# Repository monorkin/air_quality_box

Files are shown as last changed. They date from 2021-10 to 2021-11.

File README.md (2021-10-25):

# Air Quality Box

This is a [ESPHome](https://esphome.io/) powered (integrated
with [Home Assistant](https://www.home-assistant.io/))
in-door air quality meter with a display.

It measures:
* **CO₂ concentration**
* **Relative humidity**
* **Temperature**
* **Atmospheric pressure**
* **Air conductivity**
* **Dust particles <1µm weight concentration**
* **Dust particles <2.5µm weight concentration**
* **Dust particles <4µm weight concentration**
* **Dust particles <10µm weight concentration**

## Assembly

This project is split into three parts, each with it's own steps:
1. [Printed circuit board](./pcb/)
2. [Firmware](./firmware/)
3. [3D printed case](./case/)

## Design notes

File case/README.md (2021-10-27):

# Case

The case houses all components in an enclosure that can be hung from a wall or
which can sit on a table.

It also enables secure mounting of some sensors by providing screw anchors for
them.

## Development

The case is developed using [FreeCad](https://www.freecadweb.org/downloads.php).
The project also contains STL files for each component of the case.

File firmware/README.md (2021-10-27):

# Firmware

The firmware is a program that drives all sensors, connects to your WiFi
network, does OTA updates, and interacts with Home Assistant.

It's a single piece of software that controls all the device does.

## Building & flashing the firmware

The firmware is built and flashed using the
[`esphome` tool](https://esphome.io/guides/getting_started_command_line.html).

Once `esphome` is installed on your machine, open a terminal and navigate to
the `/firmware` directory of this project.

First, we want to configure the passwords for your device. These include your
WiFi password so that the device can connect to your network.

To do this, copy the `secrets.sample.yaml` file, paste it to the directory and
rename it to `secrets.yaml`. Open it in any editor and change the values to
your liking.

Second, we have to build and flash the firmware.
To do that, connect the device to your computer via USB, then run
`esphome run ./air_quality_box.yaml`. The tool will go through the
process of fetching all dependencies, building and flashing the firmware to the
device.

When prompted with a question of how you want to flash the device
(via WiFi/OTA or USB) choose USB and hit `Enter`.

The process will show you a percentage progress indicator, once it reaches
`100%` the device is ready to use, but the process won't terminate and will
display you all logs form the device. You can just `Ctrl`+`C` out of the
process at that point and un-plug the device.

## Updating the firmware

To update the firmware you just have to run `esphome run ./air_quality_box.yaml`
again.

If your device is connected to the same WiFi as your computer then you can
choose `Wifi`, or `OTA`, or `air-quality-box.local` from the prompt.

If the device isn't connected to you WiFi then you will have to connect it via
USB.

## Troubleshooting

### SPS30 (particle/dust sensor) reading abnormally high values

This can be a problem with sensors bought from some sellers.

The readings are abnormally high because the sensor is full of dust (which got
there either while shipping, storage or acquisition).

To fix this the auto-cleaning routine needs to be run on the device.
This can be done manually, but it's also configured to run after the device
has been powered on for longer than 7 days.

The ESPHome SPS30 component currently doesn't support triggering auto-cleaning
nor changing the auto-cleaning interval. Therefore, if you want to change these
values you will have to install the
[Arduino IDE](https://www.arduino.cc/en/software)
on your machine,
add [paulvha's SPS30 library](https://github.com/paulvha/sps30),
and then flash the
[Example 2: SPS30 Basic Readings - Auto-clean](https://github.com/paulvha/sps30/blob/master/examples/Example2_sps30_BasicReadings_autoclean/Example2_sps30_BasicReadings_autoclean.ino)
sketch. In it you can trigger auto-cleaning and change the auto-clean interval -
read the comments in the sketch, they will guide you through everything you need
do or set (remember to switch to I2C communication!).

### SPS30 (particle/dust sensor) reading the same value for all or some particle size ranges

First, give the device some time to settle in. About 1 to 3h should be enough.

Second, this is somewhat normal depending on the relative humidity of your room.

All cheap, laser-based, particle sensors face this problem in high-humidity
environments. The particles/dust in the air absorb some of the humidity, or the
humidity can condense on the particles, which makes them look simultaneously
the correct size and larger to the sensor as they scatter and diffract light.

This artificially inflates the numbers of larger particles to the point that
they can be the same as the numbers of smaller particles (up to the 2nd decimal).

If you are concerned about your sensor not working correctly, check the device
logs using `esphome logs ./air_quality_box.yaml` to see all 6 decimal places for
each measurement. They should be different somewhere after the 2nd decimal
place.

Note that all values after the 2nd decimal place in a reading are mostly noise
and are therefore discarded.

### MH-Z19B (CO₂ sensor) reading abnormally high or low values

Initial high readings are normal for this sensor. It will need about 1 to 3h so
settle in and auto-calibrate itself.

Just be patient.

### MH-Z19B (CO₂ sensor) flat-lines at 400ppm

That's a limitation of the sensor. It can't measure anything below 400ppm CO₂.

### The device doesn't show up in Home Assistant

Double check that you entered your WiFi credentials correctly in `secrets.yaml`.

If the device failed to connect to your WiFi it will create it's own hotspot
names `Air-Quality-Box Fallback Hotspot`. Try looking for it and connecting to
it to configure the WiFi credentials correctly, or try correcting them in
`secrets.yaml` and re-flashing the device with
`esphome run ./air_quality_box.yaml`.

Also, check that Home Assistant can see and communicate with the devices on
the WiFi network you connected this device to.

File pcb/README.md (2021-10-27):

# PCB

The PCB connects all components into a single device.
It routes power and signals from the micro-controller to each sensor, and it
does some basic power filtering.

## Development

The PCB is developed using [KiCad v5](https://www.kicad.org/download/).
All symbols, footprints and models can only be from the standard library or
contained within this project.

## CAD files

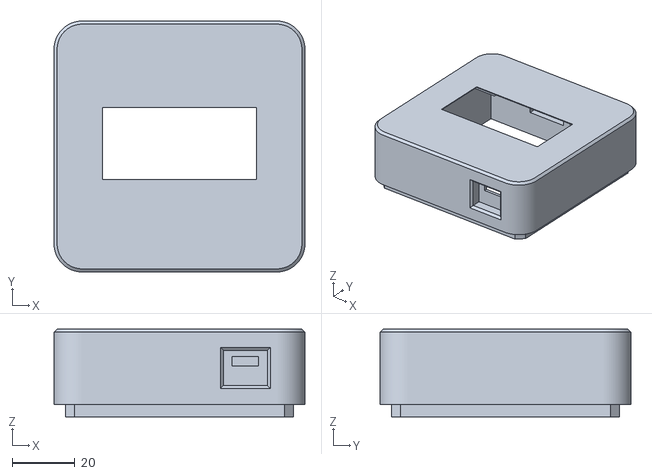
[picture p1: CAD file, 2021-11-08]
case/out/air_qualty_box-top_piece_whole.stl
80.0 x 80.0 x 28.0

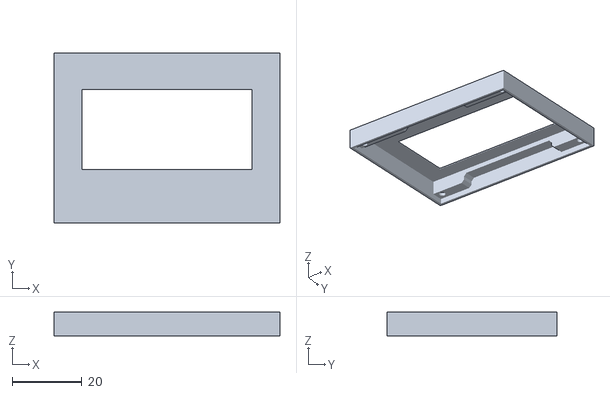
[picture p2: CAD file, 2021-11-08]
case/out/air_qualty_box-top_piece.stl
65.0 x 49.0 x 6.80

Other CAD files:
case/air_qualty_box.FCStd

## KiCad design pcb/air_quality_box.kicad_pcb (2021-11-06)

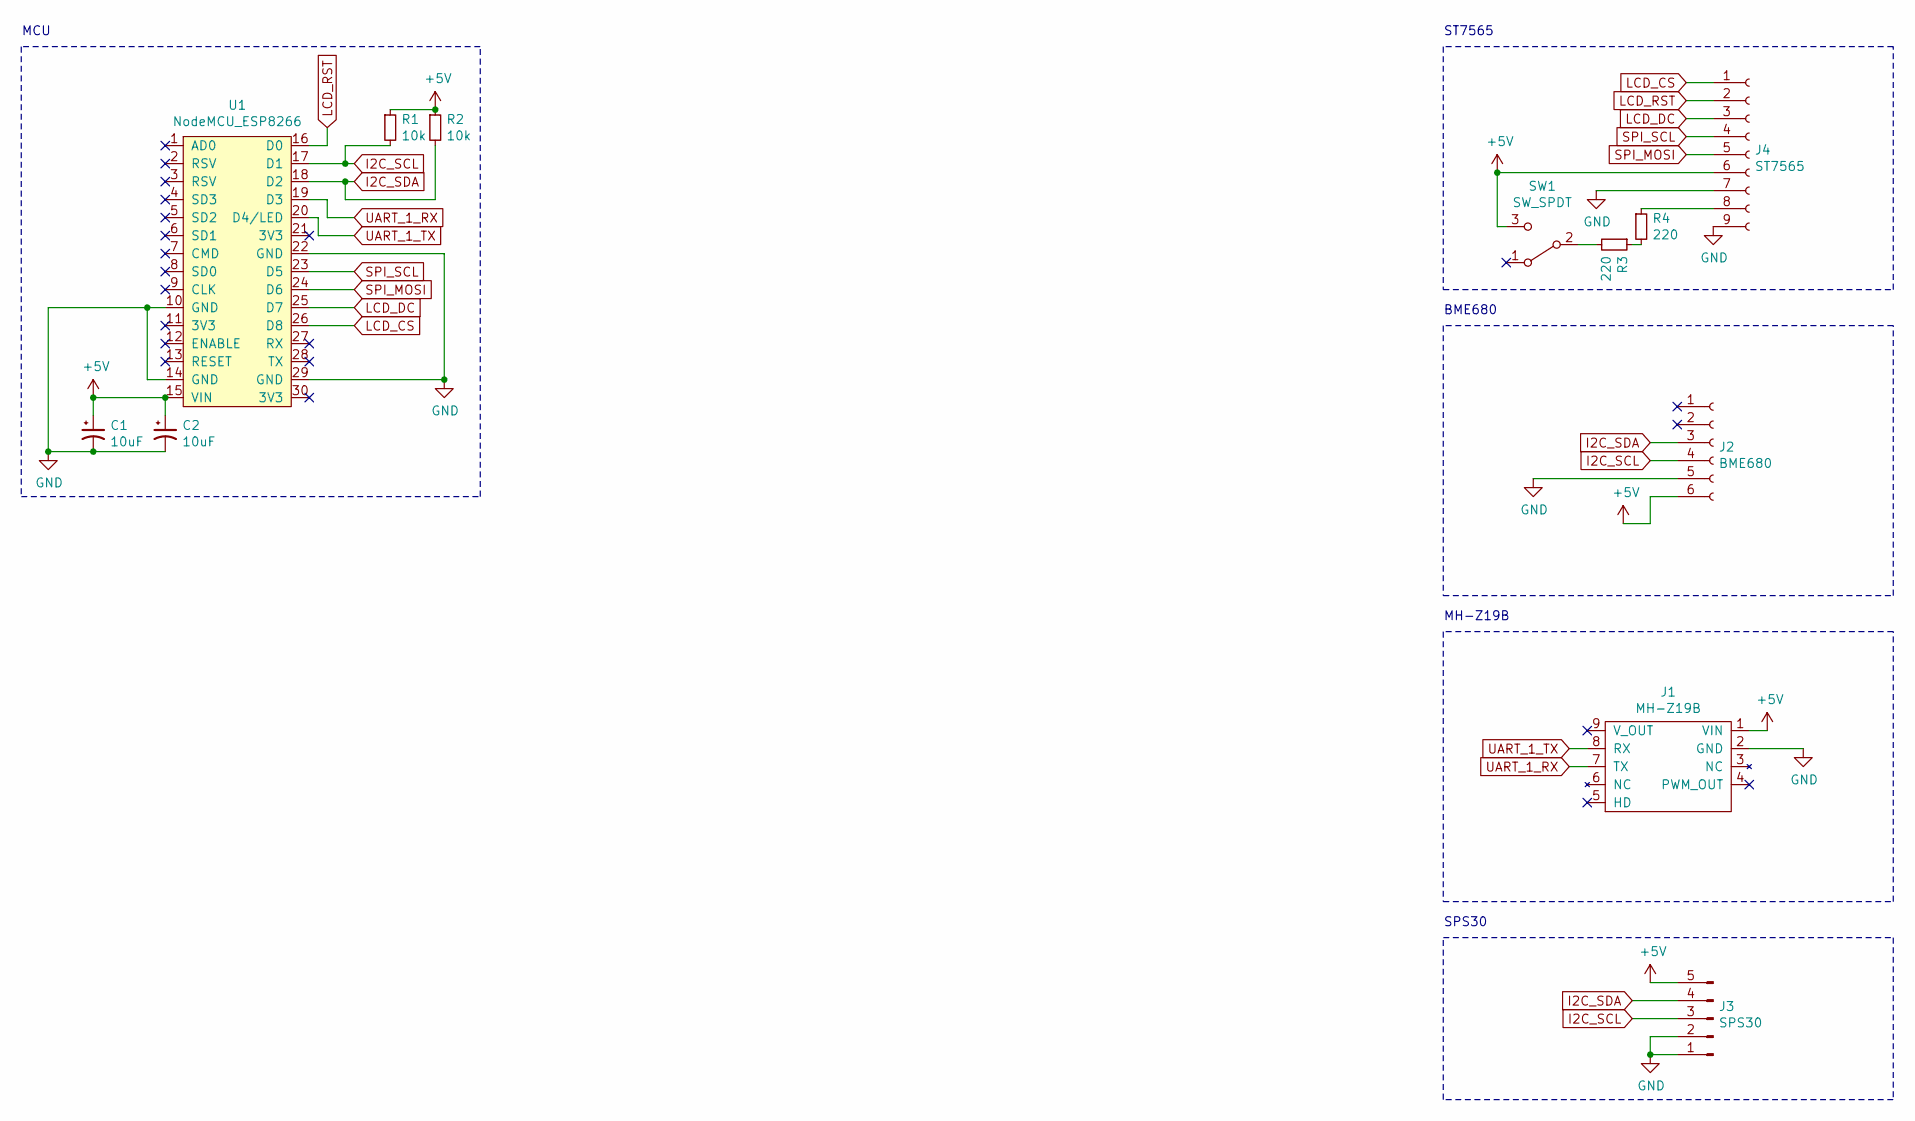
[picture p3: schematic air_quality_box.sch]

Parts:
C1, C2: 10uF; CP_Radial_D5.0mm_P2.50mm
J1: MH-Z19B
J2: BME680; PinHeader_1x06_P2.54mm_Vertical
J3: SPS30; ZH_1.5mm_5P
J4: ST7565; PinHeader_1x09_P2.54mm_Vertical
R1, R2: 10k; R_Axial_DIN0207_L6.3mm_D2.5mm_P10.16mm_Horizontal
R3, R4: 220; R_Axial_DIN0207_L6.3mm_D2.5mm_P10.16mm_Horizontal
SW1: SW_SPDT; switch
U1: NodeMCU_ESP8266

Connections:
+5V: C1.1, C2.1, J1.1 (VIN), J2.6, J3.5, J4.6, R1.1, R2.1, SW1.3 (C), U1.15 (VIN)
GND: C1.2, C2.2, J1.2 (GND), J2.5, J3.1, J3.2, J4.7, J4.9, U1.10 (GND), U1.14 (GND), U1.22 (GND), U1.29 (GND)
I2C_SCL: J2.4, J3.3, R1.2, U1.17 (D1)
I2C_SDA: J2.3, J3.4, R2.2, U1.18 (D2)
LCD_CS: J4.1, U1.26 (D8)
LCD_DC: J4.3, U1.25 (D7)
LCD_RST: J4.2, U1.16 (D0)
unnamed: J4.8, R4.1
unnamed: R3.1, R4.2
unnamed: R3.2, SW1.2 (B)
SPI_MOSI: J4.5, U1.24 (D6)
SPI_SCL: J4.4, U1.23 (D5)
UART_1_RX: J1.7 (TX), U1.19 (D3)
UART_1_TX: J1.8 (RX), U1.20 (D4/LED)

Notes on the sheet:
ST7565
BME680
MH-Z19B
SPS30
MCU

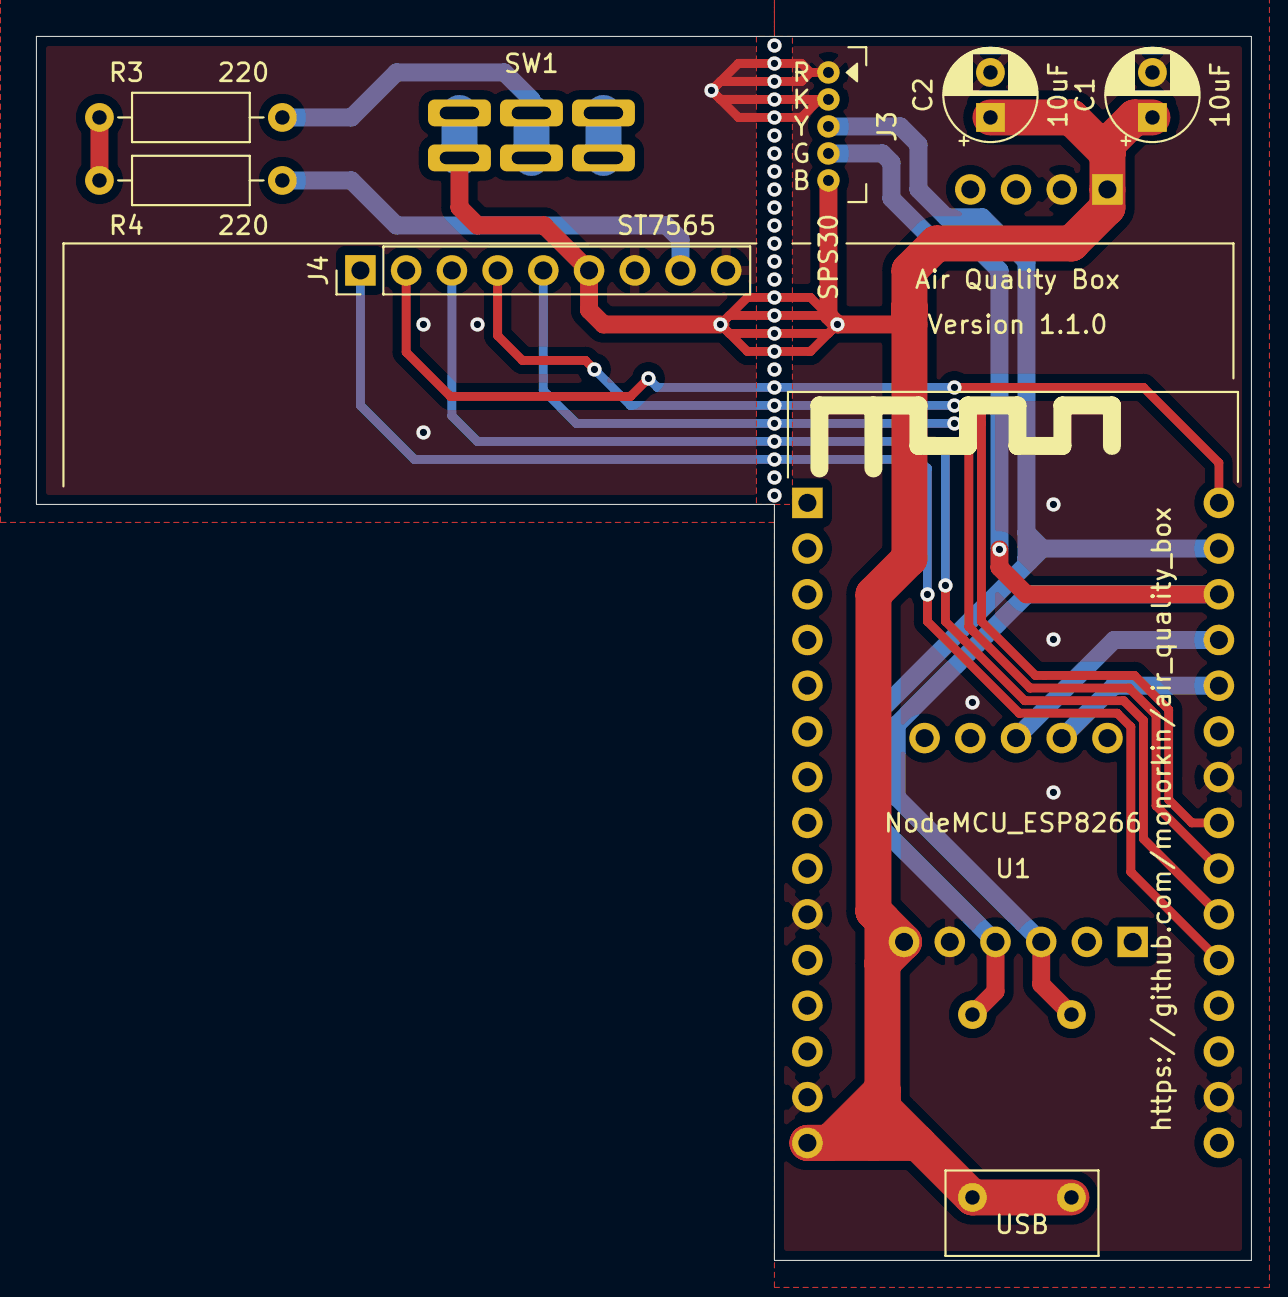
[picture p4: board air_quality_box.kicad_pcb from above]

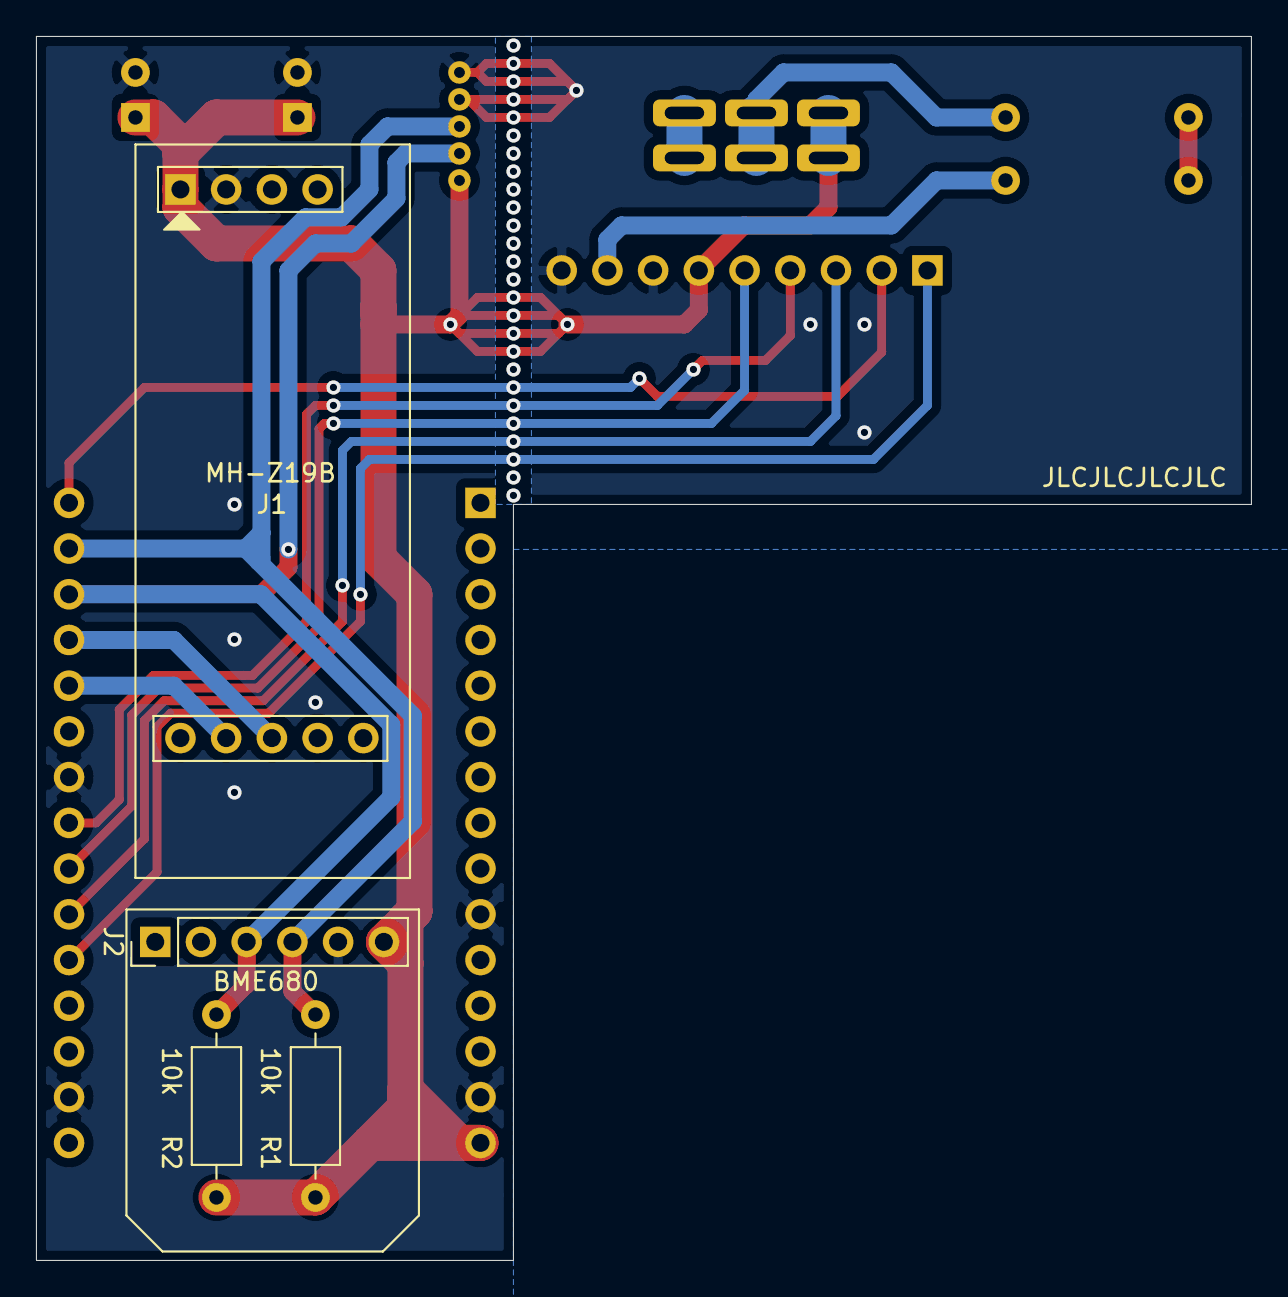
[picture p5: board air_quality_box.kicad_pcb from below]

Board: 2 copper layers, 67.5 x 68.0 mm, 12 parts (4 on the bottom side), 14 nets.

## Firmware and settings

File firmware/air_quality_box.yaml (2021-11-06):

# Import more components
external_components:
  - source: github://monorkin/esphome_st7565@main
    components: [ st7565 ]

# Project configuration
esphome:
  name: air-quality-box
  platform: ESP8266
  board: nodemcuv2

# Enable logging
logger:
  level: DEBUG

# Enable Home Assistant API
api:
  password: !secret api_password

ota:
  password: !secret ota_password

wifi:
  ssid: !secret wifi_ssid
  password: !secret wifi_password

  # Enable fallback hotspot (captive portal) in case wifi connection fails
  ap:
    ssid: "Air-Quality-Box Fallback Hotspot"
    password: !secret ap_password

captive_portal:

# Configure I2C busses
i2c:
  - sda: D2
    scl: D1
    scan: true
    id: primary_i2c_bus

# Configure serial lines
uart:
  - rx_pin: D3
    tx_pin: D4
    baud_rate: 9600
    id: mhz19b_serial

# Configure SPI busses
spi:
  - clk_pin: D5
    mosi_pin: D6
    id: primary_spi_bus

# Import fonts
font:
  - file: "fonts/Roboto-Regular.ttf"
    id: my_font
    size: 15
    glyphs: "!\"%()+=,-_.:°0123456789ABCDEFGHIJKLMNOPQRSTUVWXYZ abcdefghijklmnopqrstuvwxyz³µ#</"

# Setup displays
display:
  - platform: st7565
    id: primary_display
    spi_id: primary_spi_bus
    width: 128
    height: 64
    dc_pin:
      number: D7
    cs_pin:
      number: D8
    reset_pin:
      number: D0
    # rotation: 180
    pages:
      - id: temp_page
        lambda: |-
          it.print(0, 0, id(my_font), "TEMPERATURE");
          if (isnan(id(temp_sensor).state)) {
            it.print(0, 20, id(my_font), "Gathering data...");
          }
          else {
            float value = id(temp_sensor).state;

            char* dangerLevel = (char*)malloc(sizeof(char) * 6);
            if (value > 40) { strcpy(dangerLevel, "(!!!)"); }
            else if (value > 35) { strcpy(dangerLevel, "(!!)"); }
            else if (value > 30) { strcpy(dangerLevel, "(!)"); }
            else if (value < 5) { strcpy(dangerLevel, "(!!!)"); }
            else if (value < 10) { strcpy(dangerLevel, "(!!)"); }
            else if (value < 15) { strcpy(dangerLevel, "(!)"); }
            else { strcpy(dangerLevel, ""); }

            it.printf(0, 20, id(my_font), "%.1f°C %s", value, dangerLevel);
            it.graph(0, 40, id(temp_graph));

            free(dangerLevel);
          }
      - id: humidity_page
        lambda: |-
          it.print(0, 0, id(my_font), "HUMIDITY");
          if (isnan(id(humidity_sensor).state)) {
            it.print(0, 20, id(my_font), "Gathering data...");
          }
          else {
            float value = id(humidity_sensor).state;

            char* dangerLevel = (char*)malloc(sizeof(char) * 6);
            if (value > 70) { strcpy(dangerLevel, "(!!!)"); }
            else if (value > 65) { strcpy(dangerLevel, "(!!)"); }
            else if (value > 60) { strcpy(dangerLevel, "(!)"); }
            else if (value < 20) { strcpy(dangerLevel, "(!!!)"); }
            else if (value < 25) { strcpy(dangerLevel, "(!!)"); }
            else if (value < 30) { strcpy(dangerLevel, "(!)"); }
            else { strcpy(dangerLevel, ""); }

            it.printf(0, 20, id(my_font), "%.1f%% %s", value, dangerLevel);
            it.graph(0, 40, id(humidity_graph));

            free(dangerLevel);
          }
      - id: pressure_page
        lambda: |-
          it.print(0, 0, id(my_font), "PRESSURE");
          if (isnan(id(pressure_sensor).state)) {
            it.print(0, 20, id(my_font), "Gathering data...");
          }
          else {
            it.printf(0, 20, id(my_font), "%.1f hPa", id(pressure_sensor).state);
            it.graph(0, 40, id(pressure_graph));
          }
      - id: co2_page
        lambda: |-
          it.print(0, 0, id(my_font), "CO2");
          if (isnan(id(co2_sensor).state)) {
            it.print(0, 20, id(my_font), "Gathering data...");
          }
          else {
            float value = id(co2_sensor).state;

            char* dangerLevel = (char*)malloc(sizeof(char) * 6);
            if (value > 2000) { strcpy(dangerLevel, "(!!!)"); }
            else if (value > 1000) { strcpy(dangerLevel, "(!!)"); }
            else if (value > 800) { strcpy(dangerLevel, "(!)"); }
            else { strcpy(dangerLevel, ""); }

            it.printf(0, 20, id(my_font), "%.0f ppm %s", value, dangerLevel);
            it.graph(0, 40, id(co2_graph));

            free(dangerLevel);
          }
      - id: part_matter_1um_page
        lambda: |-
          it.print(0, 0, id(my_font), "DUST <1µm");
          if (isnan(id(PM_1_0).state) || isnan(id(PMC_1_0).state)) {
            it.print(0, 20, id(my_font), "Gathering data...");
          }
          else {
            float value = id(PM_1_0).state;

            char* dangerLevel = (char*)malloc(sizeof(char) * 6);
            if (value > 55.5) { strcpy(dangerLevel, "(!!!)"); }
            else if (value > 35.5) { strcpy(dangerLevel, "(!!)"); }
            else if (value > 12.1) { strcpy(dangerLevel, "(!)"); }
            else { strcpy(dangerLevel, ""); }
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

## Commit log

2021-10-24 Switch I2C lines
    The Node modules have dedicated I2C hardware on pins D1 (SCL) and D2
    (SDA). To avoide possbile conflicts and improve interoperability with
    3rd party libraries the configuration was updated to use these lines
    as well.
    [air_quality_box.yaml]
2021-10-25 Create sample secrets file
2021-10-27 Create board schematic
    [air_quality_box.kicad_pcb, air_quality_box.sch]
2021-10-27 Create footprints
    [air_quality_box.kicad_pcb, air_quality_box.sch]
2021-10-28 Create basic board layout
    [air_quality_box.kicad_pcb, air_quality_box.sch]
2021-10-29 Position the LCD in the center of the board
    [air_quality_box.kicad_pcb]
2021-10-29 Add JCL order number location to board
    [air_quality_box.kicad_pcb]
2021-10-29 Export Gerber and drill files
    [air_quality_box-B_Cu.gbr, air_quality_box-B_Mask.gbr, air_quality_box-B_Paste.gbr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]
2021-11-06 Swap VCC and GNC pins on BME680
    This mistake nearly cost me the sensor. To my luck only the regulator
    released the magick smoke. After replacing the regulator the sensor
    started working again.
    Also, the screen diode draws a lot of current. Through experimentation I
    figured out that it's bright enough with just 15mA of current. So I
    added a 440 Ohm load in series with the backlight to limit the current
    to about that value. This made also all sensor readings more stable, as
    the MH-Z19 sensor draws up-to 100mA which brown-outs the MCU and other
    sensors. Lowering the LCD current draw fixed that problem as well.
    [air_quality_box-B_Cu.gbr, air_quality_box-B_Mask.gbr, air_quality_box-B_Paste.gbr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]
2021-11-06 Swap DC and CS pins as they are swapped on the PCB
    [air_quality_box.yaml]
2021-11-06 Change route so that power lanes do not cross
    [air_quality_box-B_Cu.gbr, air_quality_box-B_Mask.gbr, air_quality_box-B_Paste.gbr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]
2021-11-08 Basic front face layout
    [air_qualty_box-top_piece.stl, air_qualty_box-top_piece_whole.stl, air_qualty_box.FCStd]
